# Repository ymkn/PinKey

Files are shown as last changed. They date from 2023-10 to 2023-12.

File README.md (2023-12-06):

# PinKey

A condensed 60% hot swappable custom mechanical keyboard powered by RP2040-Zero.

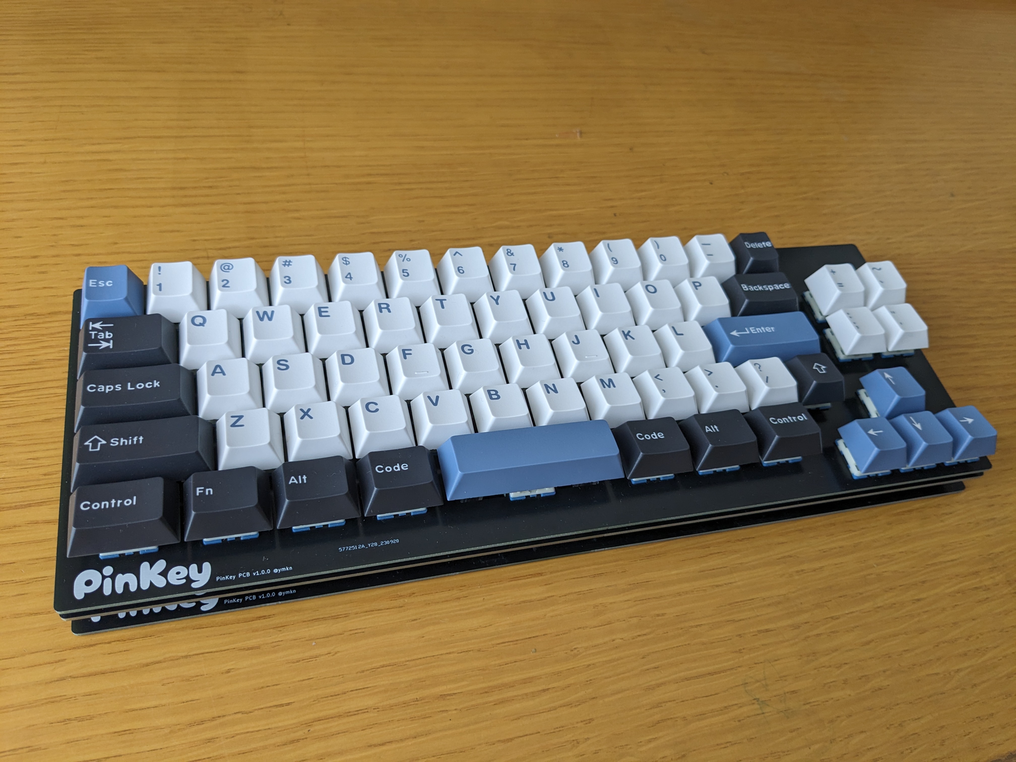
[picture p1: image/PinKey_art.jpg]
PinKey Art


## Default Layout

You can customize the layout with [Vial](https://get.vial.today/) configurator.

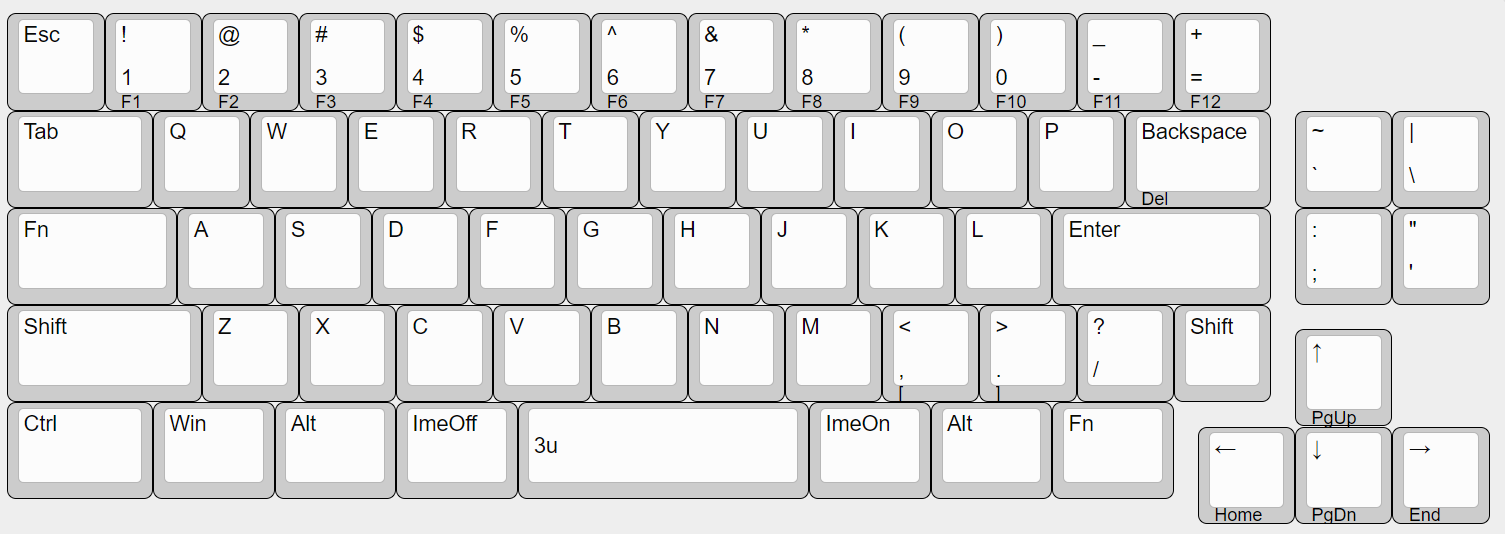
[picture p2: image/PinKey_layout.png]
PinKey Layout


Spacebar can be swap 3u to 2.25/2.75u with 2u stabilizers if you don't have 3u spacebar and its stabilizers.

## Build Guide

See [doc/buildguide.md](doc/buildguide.md)

## LICENSE

This project is licensed under the MIT License, see the [LICENSE file](LICENSE) for details.

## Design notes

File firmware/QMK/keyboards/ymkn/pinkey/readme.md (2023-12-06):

# PinKey

PinKey - A condensed 60% size keyboard.

* Keyboard Maintainer: [ymkn](https://github.com/ymkn)

Make example for this keyboard (after setting up your build environment):

    make ymkn/pinkey:vial

Flashing example for this keyboard:

1. Enter the bootloader.
2. Simply copy ymkn_pinkey_vial.uf2 to RPI_RP2 drive.

This keyboard supports [Vial](https://get.vial.today/) configurator.

## Bootloader

Enter the bootloader in 2 ways:

* **Bootmagic reset**: Hold down the key at (0,0) in the matrix (usually the top left key or Escape) and plug in the keyboard
* **Physical reset button**: Briefly press the button on the back of the PCB - some may have pads you must short instead

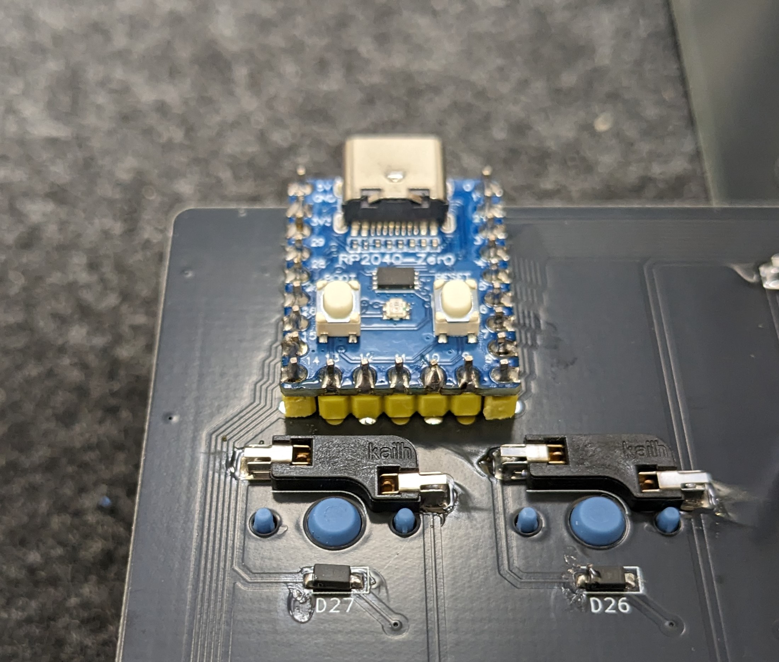
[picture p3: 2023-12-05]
image/PinKey_RP2040-Zero.jpg

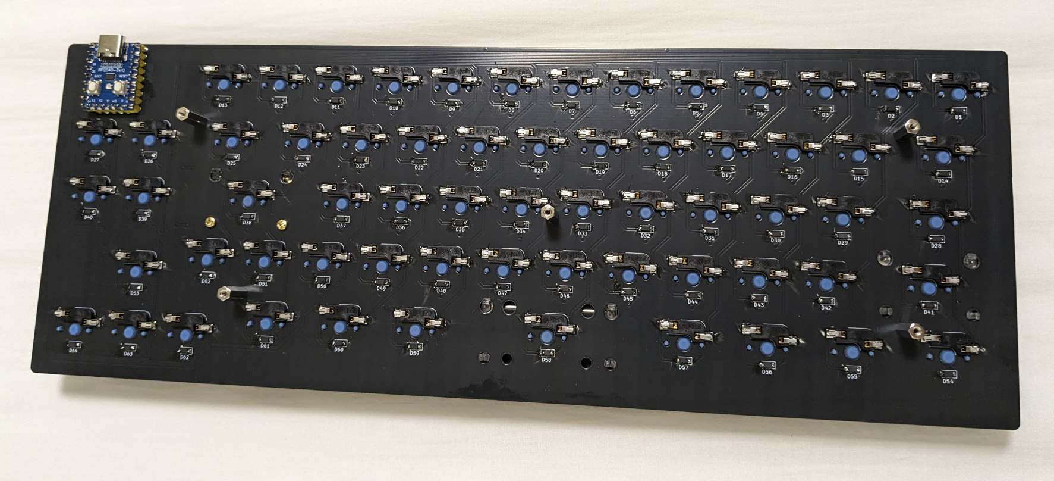
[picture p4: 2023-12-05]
image/PinKey_back.png

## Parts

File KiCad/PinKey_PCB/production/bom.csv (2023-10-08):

Designator | Footprint | Quantity | Value | LCSC Part #
D1, D10, D11, D12, D13, D14, D15, D16, D17, D18, D19, D2, D20, D21, D22, D23, D24, D25, D26, D27, D28, D29, D3, D30, D31, D32, D33, D34, D35, D36, D37, D38, D39, D4, D40, D41, D42, D43, D44, D45, D46, D47, D48, D49, D5, D50, D51, D52, D53, D54, D55, D56, D57, D58, D59, D6, D60, D61, D62, D63, D64, D7, D8, D9 | D_SOD-123 | 64 | 1N4148W
SW1, SW10, SW11, SW12, SW13, SW15, SW16, SW17, SW18, SW19, SW2, SW20, SW21, SW22, SW23, SW24, SW26, SW27, SW29, SW3, SW30, SW31, SW32, SW33, SW34, SW35, SW36, SW37, SW39, SW4, SW40, SW42, SW43, SW44, SW45, SW46, SW47, SW48, SW49, SW5, SW50, SW51, SW52, SW53, SW6, SW62, SW63, SW64, SW7, SW8, SW9 | SW_Hotswap_Kailh_MX_1.00u | 51 | SW_Push
SW14, SW25, SW54 | SW_Hotswap_Kailh_MX_1.50u | 3 | SW_Push
SW28 | SW_Hotswap_Kailh_MX_1.75u | 1 | SW_Push
SW38 | SW_Hotswap_Kailh_MX_2.25u | 1 | SW_Push
SW41 | SW_Hotswap_Kailh_MX_2.00u | 1 | SW_Push
SW55, SW56, SW57, SW59, SW60, SW61 | SW_Hotswap_Kailh_MX_1.25u | 6 | SW_Push
SW58 | SW_Hotswap_Kailh_MX_3.00u | 1 | SW_Push
U1 | rp2040-zero-tht | 1 | rp2040-zero

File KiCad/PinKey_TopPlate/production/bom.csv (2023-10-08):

Designator | Footprint | Quantity | Value | LCSC Part #
SW1, SW10, SW11, SW12, SW13, SW15, SW16, SW17, SW18, SW19, SW2, SW20, SW21, SW22, SW23, SW24, SW26, SW27, SW29, SW3, SW30, SW31, SW32, SW33, SW34, SW35, SW36, SW37, SW39, SW4, SW40, SW42, SW43, SW44, SW45, SW46, SW47, SW48, SW49, SW5, SW50, SW51, SW52, SW53, SW58, SW6, SW62, SW63, SW64, SW7, SW8, SW9 | SW_Hole_1u | 52 | SW_Push
SW14, SW25, SW54 | SW_Hole_1.5u | 3 | SW_Push
SW28 | SW_Hole_1.75u | 1 | SW_Push
SW38 | SW_Hole_2.25u | 1 | SW_Push
SW41 | SW_Hole_2u | 1 | SW_Push
SW55, SW56, SW57, SW59, SW60, SW61 | SW_Hole_1.25u | 6 | SW_Push

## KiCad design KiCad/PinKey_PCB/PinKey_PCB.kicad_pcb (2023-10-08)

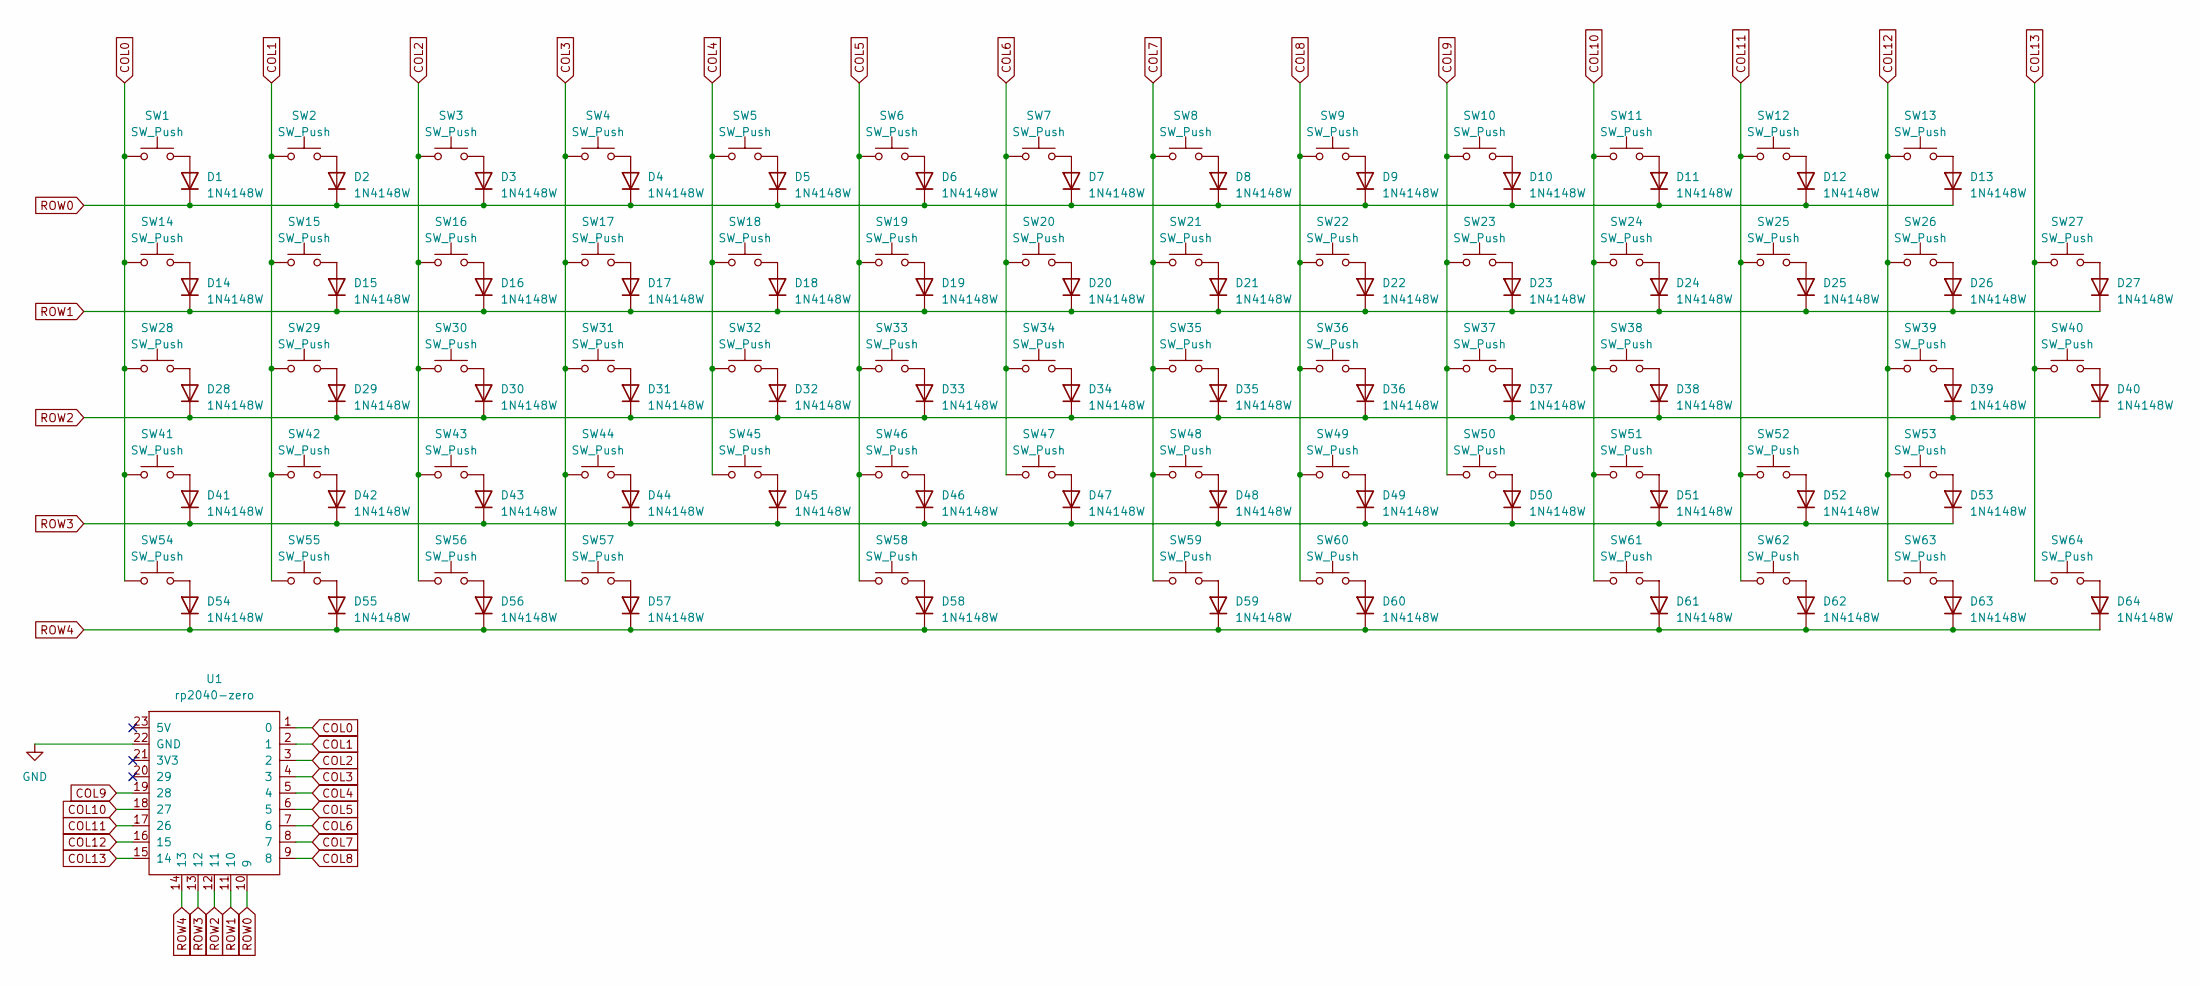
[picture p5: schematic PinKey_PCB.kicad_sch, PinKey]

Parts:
D1, D2, D3, D4, D5, D6, D7, D8, D9, D10, D11, D12, D13, D14, D15, D16, D17, D18, D19, D20, D21, D22, D23, D24, D25, D26, D27, D28, D29, D30, D31, D32, D33, D34, D35, D36, D37, D38, D39, D40, D41, D42, D43, D44, D45, D46, D47, D48, D49, D50, D51, D52, D53, D54, D55, D56, D57, D58, D59, D60, D61, D62, D63, D64: 1N4148W; D_SOD-123
SW1, SW2, SW3, SW4, SW5, SW6, SW7, SW8, SW9, SW10, SW11, SW12, SW13, SW15, SW16, SW17, SW18, SW19, SW20, SW21, SW22, SW23, SW24, SW26, SW27, SW29, SW30, SW31, SW32, SW33, SW34, SW35, SW36, SW37, SW39, SW40, SW42, SW43, SW44, SW45, SW46, SW47, SW48, SW49, SW50, SW51, SW52, SW53, SW62, SW63, SW64: SW_Push; SW_Hotswap_Kailh_MX_1.00u
SW14, SW25, SW54: SW_Push; SW_Hotswap_Kailh_MX_1.50u
SW28: SW_Push; SW_Hotswap_Kailh_MX_1.75u
SW38: SW_Push; SW_Hotswap_Kailh_MX_2.25u
SW41: SW_Push; SW_Hotswap_Kailh_MX_2.00u
SW55, SW56, SW57, SW59, SW60, SW61: SW_Push; SW_Hotswap_Kailh_MX_1.25u
SW58: SW_Push; SW_Hotswap_Kailh_MX_3.00u
U1: rp2040-zero; rp2040-zero-tht

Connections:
COL0: SW1.1, SW14.1, SW28.1, SW41.1, SW54.1, U1.1 (0)
COL1: SW2.1, SW15.1, SW29.1, SW42.1, SW55.1, U1.2 (1)
COL2: SW3.1, SW16.1, SW30.1, SW43.1, SW56.1, U1.3 (2)
COL3: SW4.1, SW17.1, SW31.1, SW44.1, SW57.1, U1.4 (3)
COL4: SW5.1, SW18.1, SW32.1, SW45.1, U1.5 (4)
COL5: SW6.1, SW19.1, SW33.1, SW46.1, SW58.1, U1.6 (5)
COL6: SW7.1, SW20.1, SW34.1, SW47.1, U1.7 (6)
COL7: SW8.1, SW21.1, SW35.1, SW48.1, SW59.1, U1.8 (7)
COL8: SW9.1, SW22.1, SW36.1, SW49.1, SW60.1, U1.9 (8)
COL9: SW10.1, SW23.1, SW37.1, SW50.1, U1.19 (28)
COL10: SW11.1, SW24.1, SW38.1, SW51.1, SW61.1, U1.18 (27)
COL11: SW12.1, SW25.1, SW52.1, SW62.1, U1.17 (26)
COL12: SW13.1, SW26.1, SW39.1, SW53.1, SW63.1, U1.16 (15)
COL13: SW27.1, SW40.1, SW64.1, U1.15 (14)
GND: U1.22 (GND)
unnamed: D1.2 (A), SW1.2
unnamed: D2.2 (A), SW2.2
unnamed: D3.2 (A), SW3.2
unnamed: D4.2 (A), SW4.2
unnamed: D5.2 (A), SW5.2
unnamed: D6.2 (A), SW6.2
unnamed: D7.2 (A), SW7.2
unnamed: D8.2 (A), SW8.2
unnamed: D9.2 (A), SW9.2
unnamed: D10.2 (A), SW10.2
unnamed: D11.2 (A), SW11.2
unnamed: D12.2 (A), SW12.2
unnamed: D13.2 (A), SW13.2
unnamed: D14.2 (A), SW14.2
unnamed: D15.2 (A), SW15.2
unnamed: D16.2 (A), SW16.2
unnamed: D17.2 (A), SW17.2
unnamed: D18.2 (A), SW18.2
unnamed: D19.2 (A), SW19.2
unnamed: D20.2 (A), SW20.2
unnamed: D21.2 (A), SW21.2
unnamed: D22.2 (A), SW22.2
unnamed: D23.2 (A), SW23.2
unnamed: D24.2 (A), SW24.2
unnamed: D25.2 (A), SW25.2
unnamed: D26.2 (A), SW26.2
unnamed: D27.2 (A), SW27.2
unnamed: D28.2 (A), SW28.2
unnamed: D29.2 (A), SW29.2
unnamed: D30.2 (A), SW30.2
unnamed: D31.2 (A), SW31.2
unnamed: D32.2 (A), SW32.2
unnamed: D33.2 (A), SW33.2
unnamed: D34.2 (A), SW34.2
unnamed: D35.2 (A), SW35.2
unnamed: D36.2 (A), SW36.2
unnamed: D37.2 (A), SW37.2
unnamed: D38.2 (A), SW38.2
unnamed: D39.2 (A), SW39.2
unnamed: D40.2 (A), SW40.2
unnamed: D41.2 (A), SW41.2
unnamed: D42.2 (A), SW42.2
unnamed: D43.2 (A), SW43.2
unnamed: D44.2 (A), SW44.2
unnamed: D45.2 (A), SW45.2
unnamed: D46.2 (A), SW46.2
unnamed: D47.2 (A), SW47.2
unnamed: D48.2 (A), SW48.2
unnamed: D49.2 (A), SW49.2
unnamed: D50.2 (A), SW50.2
unnamed: D51.2 (A), SW51.2
unnamed: D52.2 (A), SW52.2
unnamed: D53.2 (A), SW53.2
unnamed: D54.2 (A), SW54.2
unnamed: D55.2 (A), SW55.2
unnamed: D56.2 (A), SW56.2
unnamed: D57.2 (A), SW57.2
unnamed: D58.2 (A), SW58.2
unnamed: D59.2 (A), SW59.2
unnamed: D60.2 (A), SW60.2
unnamed: D61.2 (A), SW61.2
unnamed: D62.2 (A), SW62.2
unnamed: D63.2 (A), SW63.2
unnamed: D64.2 (A), SW64.2
ROW0: D1.1 (K), D2.1 (K), D3.1 (K), D4.1 (K), D5.1 (K), D6.1 (K), D7.1 (K), D8.1 (K), D9.1 (K), D10.1 (K), D11.1 (K), D12.1 (K), D13.1 (K), U1.10 (9)
ROW1: D14.1 (K), D15.1 (K), D16.1 (K), D17.1 (K), D18.1 (K), D19.1 (K), D20.1 (K), D21.1 (K), D22.1 (K), D23.1 (K), D24.1 (K), D25.1 (K), D26.1 (K), D27.1 (K), U1.11 (10)
ROW2: D28.1 (K), D29.1 (K), D30.1 (K), D31.1 (K), D32.1 (K), D33.1 (K), D34.1 (K), D35.1 (K), D36.1 (K), D37.1 (K), D38.1 (K), D39.1 (K), D40.1 (K), U1.12 (11)
ROW3: D41.1 (K), D42.1 (K), D43.1 (K), D44.1 (K), D45.1 (K), D46.1 (K), D47.1 (K), D48.1 (K), D49.1 (K), D50.1 (K), D51.1 (K), D52.1 (K), D53.1 (K), U1.13 (12)
ROW4: D54.1 (K), D55.1 (K), D56.1 (K), D57.1 (K), D58.1 (K), D59.1 (K), D60.1 (K), D61.1 (K), D62.1 (K), D63.1 (K), D64.1 (K), U1.14 (13)

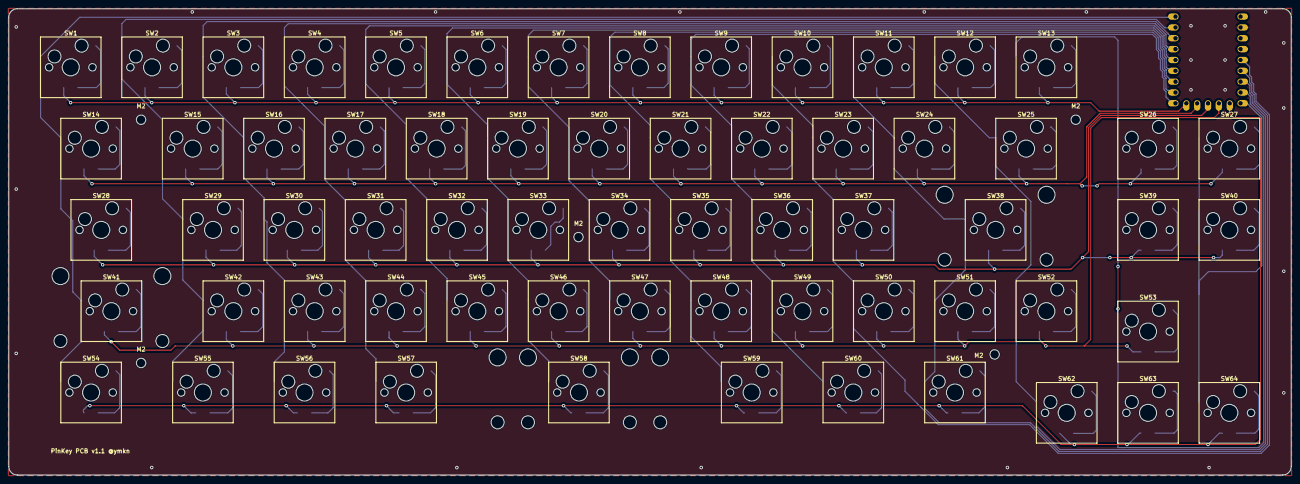
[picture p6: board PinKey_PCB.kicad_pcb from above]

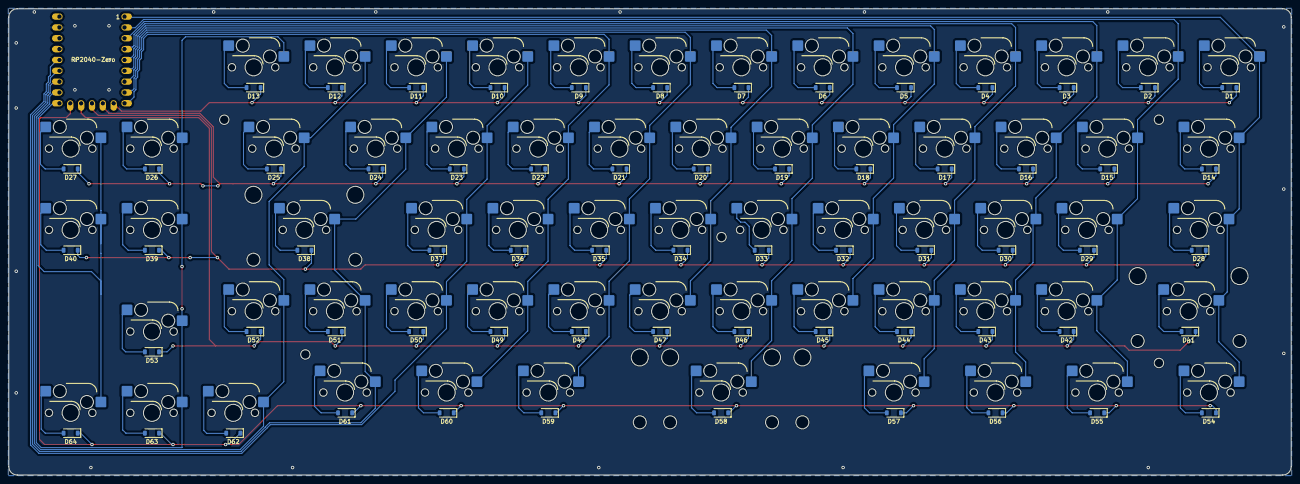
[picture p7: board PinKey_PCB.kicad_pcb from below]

Board: 2 copper layers, 300.5 x 109.2 mm, 134 parts (65 on the bottom side), 83 nets.

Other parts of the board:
M2, M2#2, M2#3, M2#4, M2#5: MountingHole_2.2mm_M2

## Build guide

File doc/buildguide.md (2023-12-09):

# PinKey ビルドガイド

## 1. はじめに

本書は自作キーボードであるPinKeyのビルドガイドです。キーボードとして利用可能になるまでの手順を初心者向けに丁寧に記載したつもりですが、不明な個所などある場合は適時検索するなどして補ってください。

申し訳ないのですがPinKey固有でない一般のご質問にはお答えできません。各自お調べください。

## 2. 準備

### 2.1 内容物確認

PinKeyは本体となる基板とキースイッチ固定用のトッププレート、底面を支えるボトムプレートのセットです。キーボードとして使用するにはその他必要な部品を別途調達いただく必要があります。

|品目|数量|
|---|---|
|PinKey 基板|1|
|PinKey トッププレート|1|
|PinKey ボトムプレート|1|
|六角スペーサー|6（予備1）|
|M2ネジ|11（予備1）|

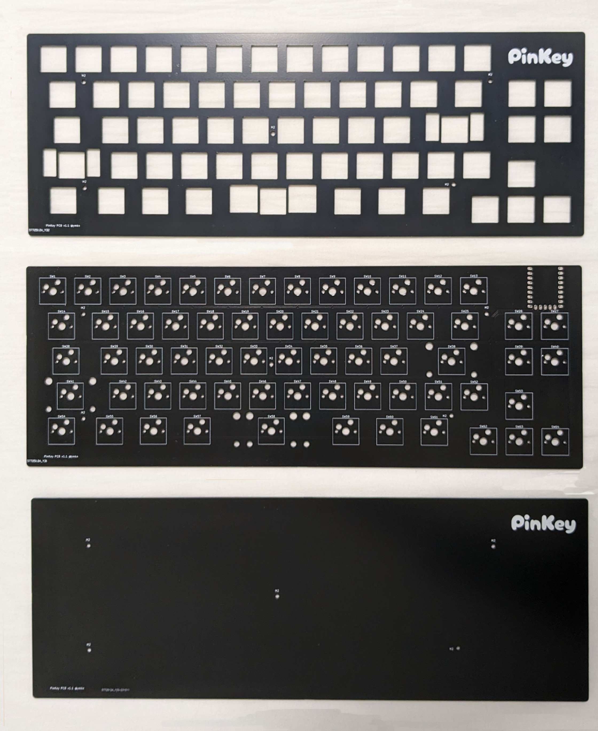
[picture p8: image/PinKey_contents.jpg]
PinKey内容物


### 2.2 別途用意が必要な部品

下記部品は国内外の自作キーボード専門店や電子部品販売店などから別途調達してください。

|品目|数量|備考|
|---|---|---|
|Waveshare RP2040-Zero|1|[Waveshare製RP2040-Zero 純正品](https://www.waveshare.com/wiki/RP2040-Zero)をお勧めします。互換品もありますが動作するかはわかりません|
|ピンヘッダ（高さ2mm、ピッチ2.54mm）|23ピン分（9x2、5x1）|RP2040-Zeroにピンヘッダが同梱されていない場合は別途用意してください|
|1N4148W ダイオード (SOD123)|64|[Diodes Incorporated社製1N4148W](https://www.diodes.com/part/view/1N4148W)もしくはその互換品|
|MX互換キースイッチ|64|[Cherry MX](https://www.cherrymx.de/en/dev.html)もしくはその互換品|
|MX互換スイッチソケット|64|[Kailh PCB Socket CPG151101S11](https://www.kailhswitch.com/mechanical-keyboard-switches/box-switches/mechanical-keyboard-switches-kailh-pcb-socket.html)もしくはその互換品|
|MX互換キーキャップ|-|[Cherry MX](https://www.cherrymx.de/en/dev.html)もしくはその互換品|
|2uサイズPCBマウント型スタビライザー|2|幅の広いキーの押し下げを安定させる部品です。左ShiftキーとEnterキーに用います|
|2u or 3uサイズPCBマウント型スタビライザー|1|幅の広いキーの押し下げを安定させる部品です。スペースキーに用います。3uスタビライザーと3uスペースキーの組み合わせが推奨です。2uスタビライザーと2.75uスペースキーの組み合わせでも代用可能ですが、隙間が空きます|

### 必要なキーキャップとサイズ

必要なキーキャップとそのサイズは下図の通りです。キーのサイズは正方形のキーの幅を「1u」と呼称します。2uであれば1uの2倍の幅のキーであることを示します。幅は0.25u刻みで様々なサイズがあります。

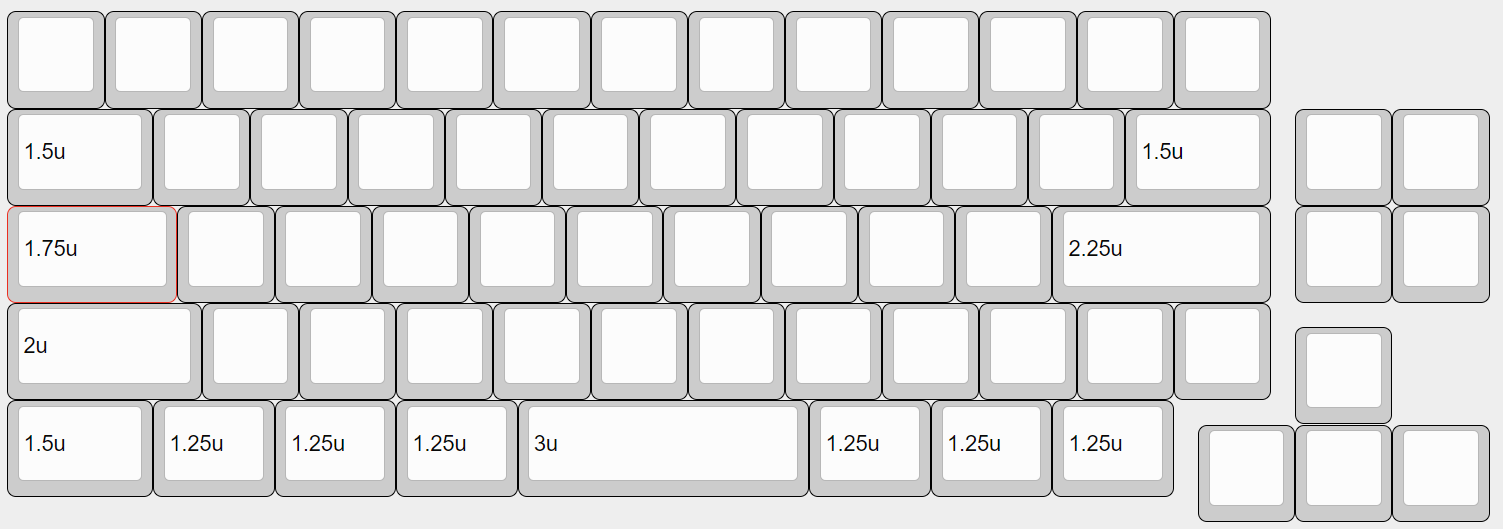
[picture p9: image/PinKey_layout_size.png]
レイアウト


このうち、標準的なANSI/ISOレイアウト向けのキーキャップセットに含まれていないか、オプション扱いであることが多い注意すべきキーは次の通りです。オプションを購入するか、同じサイズの別の印字のキーキャップで代替してください。

|行|サイズ|初期レイアウトの対応キー名|
|---|---|---|
|R2|1.5u|Backspaceキー|
|R4|2u|左Shiftキー|
|R4|1u|右Shiftキー|
|R5|1.25u|無変換、変換、Fn|
|R5|3u|スペースキー|

スペースキーは3uが推奨ですが、3uのスペースキーを用意できない場合は2.75uや2.25uでも代用できます（ただし左右に隙間が空きます）。

### 2.3 道具

|品目|数量|備考|
|---|---|---|
|はんだごて、はんだ|1|スイッチソケットのはんだ付けに用います。はんだごては調温機能付きのものを、はんだは鉛入りのものを推奨します|
|ニッパー|1|ピンヘッダの余り部分を切断するのに使います|
|ピンセット|1|スイッチソケットのはんだ付けの際にあると便利です|
|拡大鏡|1|ダイオードの向きを確認する際にあると便利です|
|テスター|1|ダイオードの導通を確認する際にあると便利です|
|ねじ回し（プラス）|1|基板とボトムプレートを固定する際に用います|

## 3. ファームウェアの書き込み

まず初めにRP2040-Zeroの動作確認と、ファームウェアの書き込みを行います。

## 3.1 ファームウェアのダウンロード

下記からファームウェアをダウンロードしてください。

https://github.com/ymkn/PinKey/blob/main/firmware/QMK/ymkn_PinKey_vial.uf2

画面右上の方に下矢印のダウンロードボタンがあるので、そこを押すことでダウンロードできます。

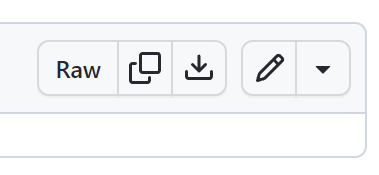
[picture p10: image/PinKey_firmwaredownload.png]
PinKeyファームウェアダウンロード


## 3.2 RP2040-Zeroの動作確認とファームウェアの書き込み

お使いのコンピュータのUSB 2.0以上に対応したUSBコネクタと、RP2040-Zeroを接続してください。RP2040-Zeroが正常であれば、`RPI-RP2`というドライブがマウントされると思います。

もしマウントされない場合は、USBケーブルを接続した状態のままRP2040-ZeroのBOOTボタンを押しながらRESETボタンを押してください。これで`RPI-RP2`というドライブがマウントされれば問題ありません。もしこれでも何も起きない場合、RP2040-Zeroが壊れている可能性があります。。。

この`RPI-RP2`というドライブに、先ほどダウンロードしたファームウェアをコピーしてください。しばらくすると`RPI-RP2`ドライブが消えますので、これでファームウェアの書き込みは完了です。USBケーブルを抜いてください。

何らかの理由でやり直したい場合は、RP2040-ZeroのBOOTボタンを押しながらRESETボタンを押すことで、再び`RPI-RP2`というドライブをマウントすることができます。

## 4. 組み立て

### 4.1 はんだ付け

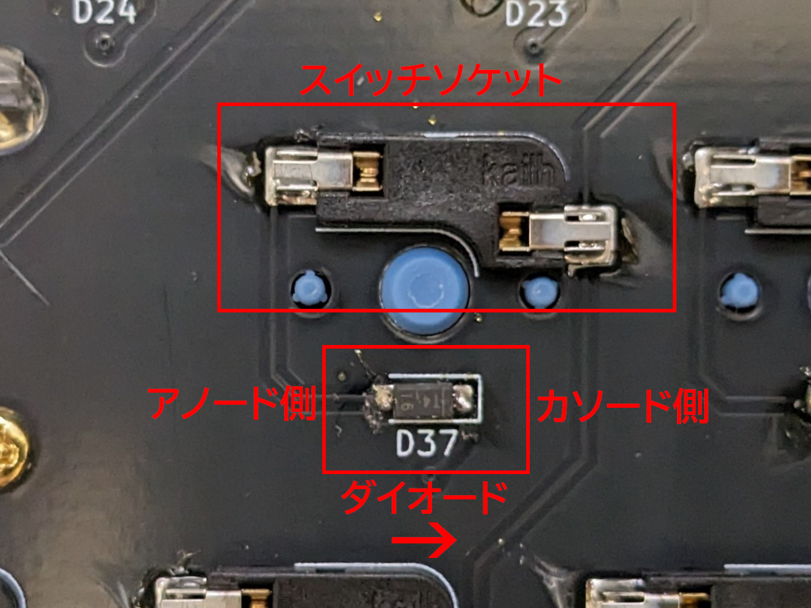
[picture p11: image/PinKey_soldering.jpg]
PinKey裏面


#### 4.1.1 ダイオードのはんだ付け

ダイオードは基板の裏面（ICチップ等が実装されている面）に取り付けます。コの字状のガイドが白線でキー数分印刷されていますので、そのすべてにダイオードをはんだ付けします。

ダイオードは向きが決まっています。ダイオード上の目印が印刷されている側（カソード側）が向かって右側になるようにしてください。

まず片足だけをはんだ付けした状態でテスターを使い導通確認をすると安心です。

すべてのダイオードが基板に密着しており、両端とも漏れなくはんだ付けされているか確認してください。基板から浮いていたり、はんだ付けができていないとキースイッチの動作不良の原因になります。

#### 4.1.2 スイッチソケットのはんだ付け

スイッチソケットもダイオードと同様に基板の裏面に取り付けます。L字状のガイドが白線でキー数分印刷されていますので、そのすべてにスイッチソケットをはんだ付けします。

すべてのスイッチソケットが基板に密着しており、ソケット両端とも漏れなくはんだ付けされているか確認してください。基板から浮いていたり、はんだ付けができていないとキースイッチの動作不良の原因になります。

#### 4.1.3 RP2040-Zeroのはんだ付け

RP2040-Zeroも同様に基板の裏面に取り付けます。基板左上のスルーホールにピンヘッダを差し込み、その上にRP2040-Zeroを差し込んだ形になるようにはんだ付けをしてください。ピンヘッダは足の長い方が基板表面側にに出るようにします。

> [!CAUTION]
> RP2040-Zeroの向きを間違えないようにしてください。写真の通り、裏面から見た時に、ボタンが見えるような向きである必要があります。表裏を間違えると動作しませんのでご注意ください。

PinKey RP2040-Zero

基板スルーホールにピンヘッダとRP2040-Zeroを通した状態で、RP2040-Zero側を先にはんだ付けしてから、基板表面側をはんだ付けすると曲がらずにやりやすいかと思います。

最後に、基板表側に飛び出した足はニッパーで短くカットしてください。ピンヘッダの長さによっては、トッププレートと干渉してしまうためです。

### 4.2 スタビライザーの取り付け

スタビライザーは基板の表面（ロゴが印刷されている面）に取り付けます。

左ShiftキーとEnterキーに2uサイズを、スペースキーに3uサイズ（2.75u以下のキーを代用する場合は2uサイズ）のスタビライザーを取り付けます。取り付け方はスタビライザーごとに異なりますが、一般には大きい穴の方にツメを引っかけ、小さい穴の方にプッシュピンを差し込む、もしくはネジ留めを行います。

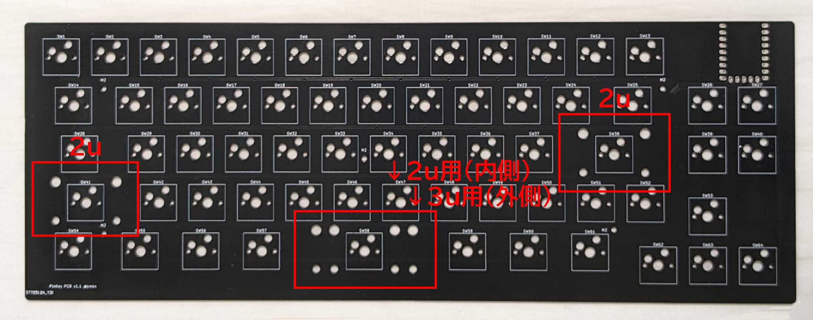
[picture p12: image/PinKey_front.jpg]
PinKey表面


### 4.3 ボトムプレートの取り付け

スイッチとトッププレートを取り付ける前に、基盤にボトムプレートを取り付けます。

M2と書かれたネジ穴が5ヶ所ありますので、基板表面からネジを差し込み、裏側から六角スペーサーを取り付けてください。

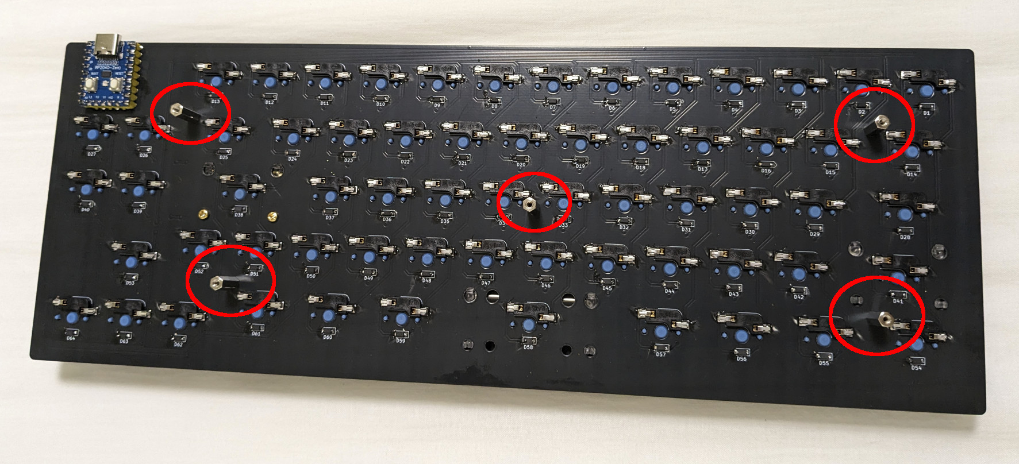
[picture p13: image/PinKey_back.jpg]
PinKeyネジ穴


六角スペーサの上にネジ穴が合うようにボトムプレートを乗せ、ボトムプレート側からネジ留めしてください。

### 4.4 スイッチとトッププレートの取り付け

キースイッチはトッププレートを通して基板のソケットに差し込みます。すべてのキースイッチを一度に取り付けてしまうと基板に差し込むのが大変なので、まずトッププレートの四隅にキースイッチを取り付けて基板に差し込み、その後残りのスイッチを取り付けていくのがおすすめです。

### 4.5 キーキャップの取り付け

全てのスイッチにキーキャップを取り付けたら完成です！

## 5. 使用

### 5.1 動作確認

コンピュータにPinKeyを接続し、文字が入力できることを確認してください。

### 5.2 キーマップのカスタマイズ

本キーボードは[Vial](https://get.vial.today/)というキーマップ変更ツールに対応しています。Vialの詳しい使いかたはVialのドキュメントや世間の情報を参考にしてください。

何らかの理由で既定のレイアウトが必要な場合は下記からVial用のレイアウトデータをダウンロードできます。

https://github.com/ymkn/PinKey/blob/main/firmware/QMK/default_layout_jp.vil

> [!WARNING]
> RP2040-Zeroをリセット（BOOTボタンを押しながらRESETボタンを押す）すると、既定のレイアウトに戻ってしまいます。

### 5.3 漢字キー（日本語入力On/Off用のキー）について

本キーボードの初期レイアウトに漢字キーの割り当てはありません。その代わり、スペースキーの左側のキーをImeOffキーに、右側のキーをImeOnキーに割り当てています。ImeOnキーとImeOffキーはWindows 10 1903以降でMicrosoft IMEを使用している場合に利用可能です。漢字キーが必要な場合はレイアウトをカスタマイズして任意のキーに割り当ててください。

参考： [キーボード日本 \- ImeOn / ImeOff の実装 \| Microsoft Learn](https://learn.microsoft.com/ja-jp/windows-hardware/design/component-guidelines/keyboard-japan-ime)

## 6. その他

### 6.1 ブートモードの入り方

RP2040のブートモードに入るには、左上のキー（Escキー）を押しながらUSBケーブルを接続します。

もしくは、RP2040-ZeroのBOOTボタンを押しながらRESETボタンを押します。

### 6.2 ソースコード/設計データのありか

本リポジトリ内で公開しています。MITライセンスです。

https://github.com/ymkn/PinKey

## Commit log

2023-10-08 v1.1 メイン部と矢印部の隙間を0.25u相当に変更
    [PinKey_BottomPlate.kicad_pcb, PinKey_PCB.kicad_pcb, PinKey_PCB.kicad_sch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]
2023-12-05 ビルドガイドの追加
2023-12-05 ロゴデータの位置変更
2023-12-06 ファームウェアの追加
2023-12-06 同梱ネジ数変更
2023-12-06 READMEとLICENSE追加
2023-12-09 ファイル名の大文字小文字の揺れを修正
2023-12-09 参照元の大文字小文字揺れを修正
2023-12-09 warning記法の誤りを修正
